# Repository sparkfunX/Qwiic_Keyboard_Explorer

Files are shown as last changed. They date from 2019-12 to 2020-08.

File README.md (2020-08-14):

Qwiic_Keyboard_Explorer
========================================

Qwiic Keyboard Explorer (https://cdn.sparkfun.com//assets/parts/1/4/8/4/8/16184-Qwiic_Keyboard_Explorer-01.jpg)

[*Qwiic Keyboard Explorer*](https://www.sparkfun.com/products/16184)

The Qwiic Keyboard Explorer is a 14-key mechanical keyboard kit based on our Qwiic Pro Micro development board. On its own, it makes a conveniently sized programmable macro pad, but we've also included plenty of prototyping space along the top for experimenting with all kinds of keyboard peripherals. If soldering isn't your thing, take advantage of the Pro Micro's Qwiic connector to attach any board from our Qwiic ecosystem! The standoff holes surrounding the prototyping area are spaced to accommodate most Qwiic boards for convenient mounting.

SparkFun labored with love to design this board. Feel like supporting open source hardware? 
Buy a [board](https://www.sparkfun.com/products/16184) from SparkFun!

Repository Contents
-------------------

* **/Hardware** - Eagle design files (.brd, .sch)
* **/Software** - Arduino Example Code

License Information
-------------------

This product is _**open source**_! 

Please review the LICENSE.md file for license information. 

If you have any questions or concerns on licensing, please contact technical support on our [SparkFun forums](https://forum.sparkfun.com/viewforum.php?f=152).

Distributed as-is; no warranty is given.

- Your friends at SparkFun.

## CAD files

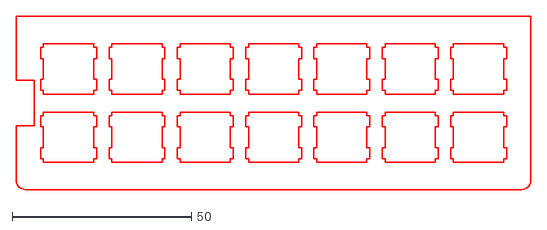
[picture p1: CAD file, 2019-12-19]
Hardware/Qwiic_Keyboard_Explorer.dxf
143.5 x 48.2

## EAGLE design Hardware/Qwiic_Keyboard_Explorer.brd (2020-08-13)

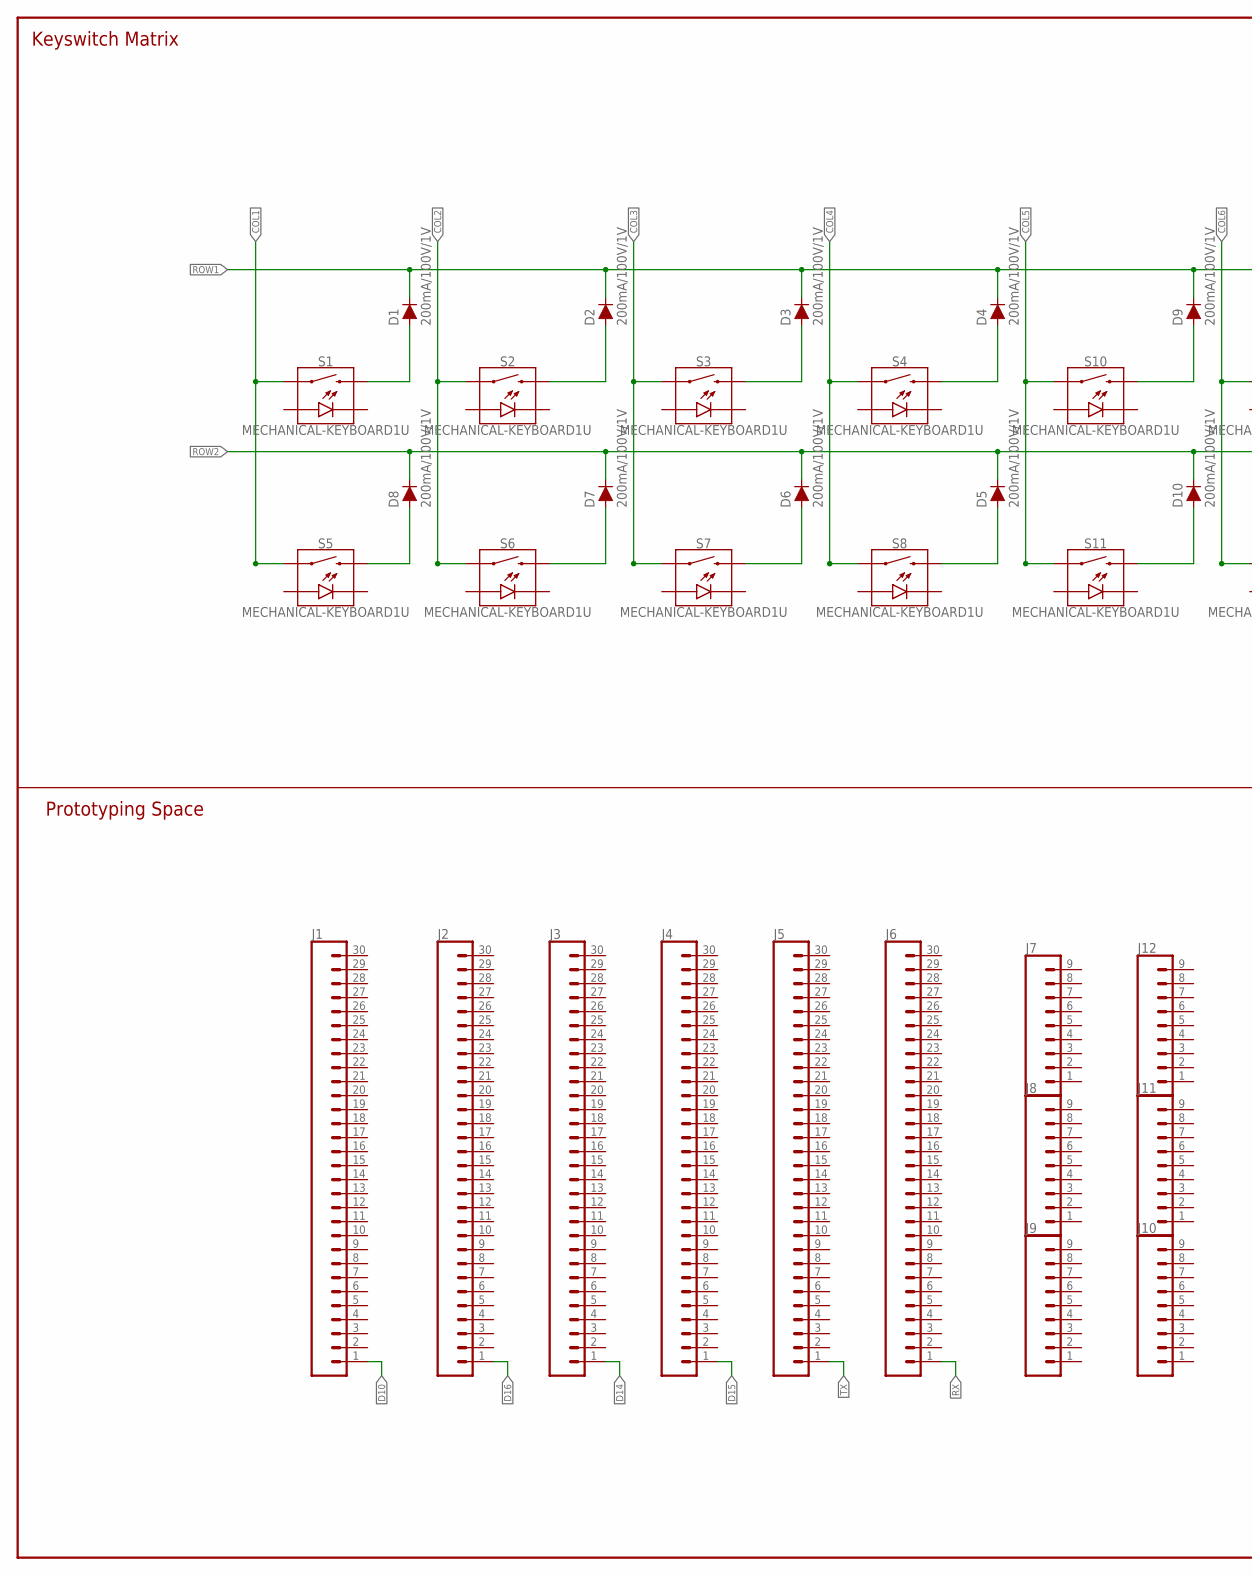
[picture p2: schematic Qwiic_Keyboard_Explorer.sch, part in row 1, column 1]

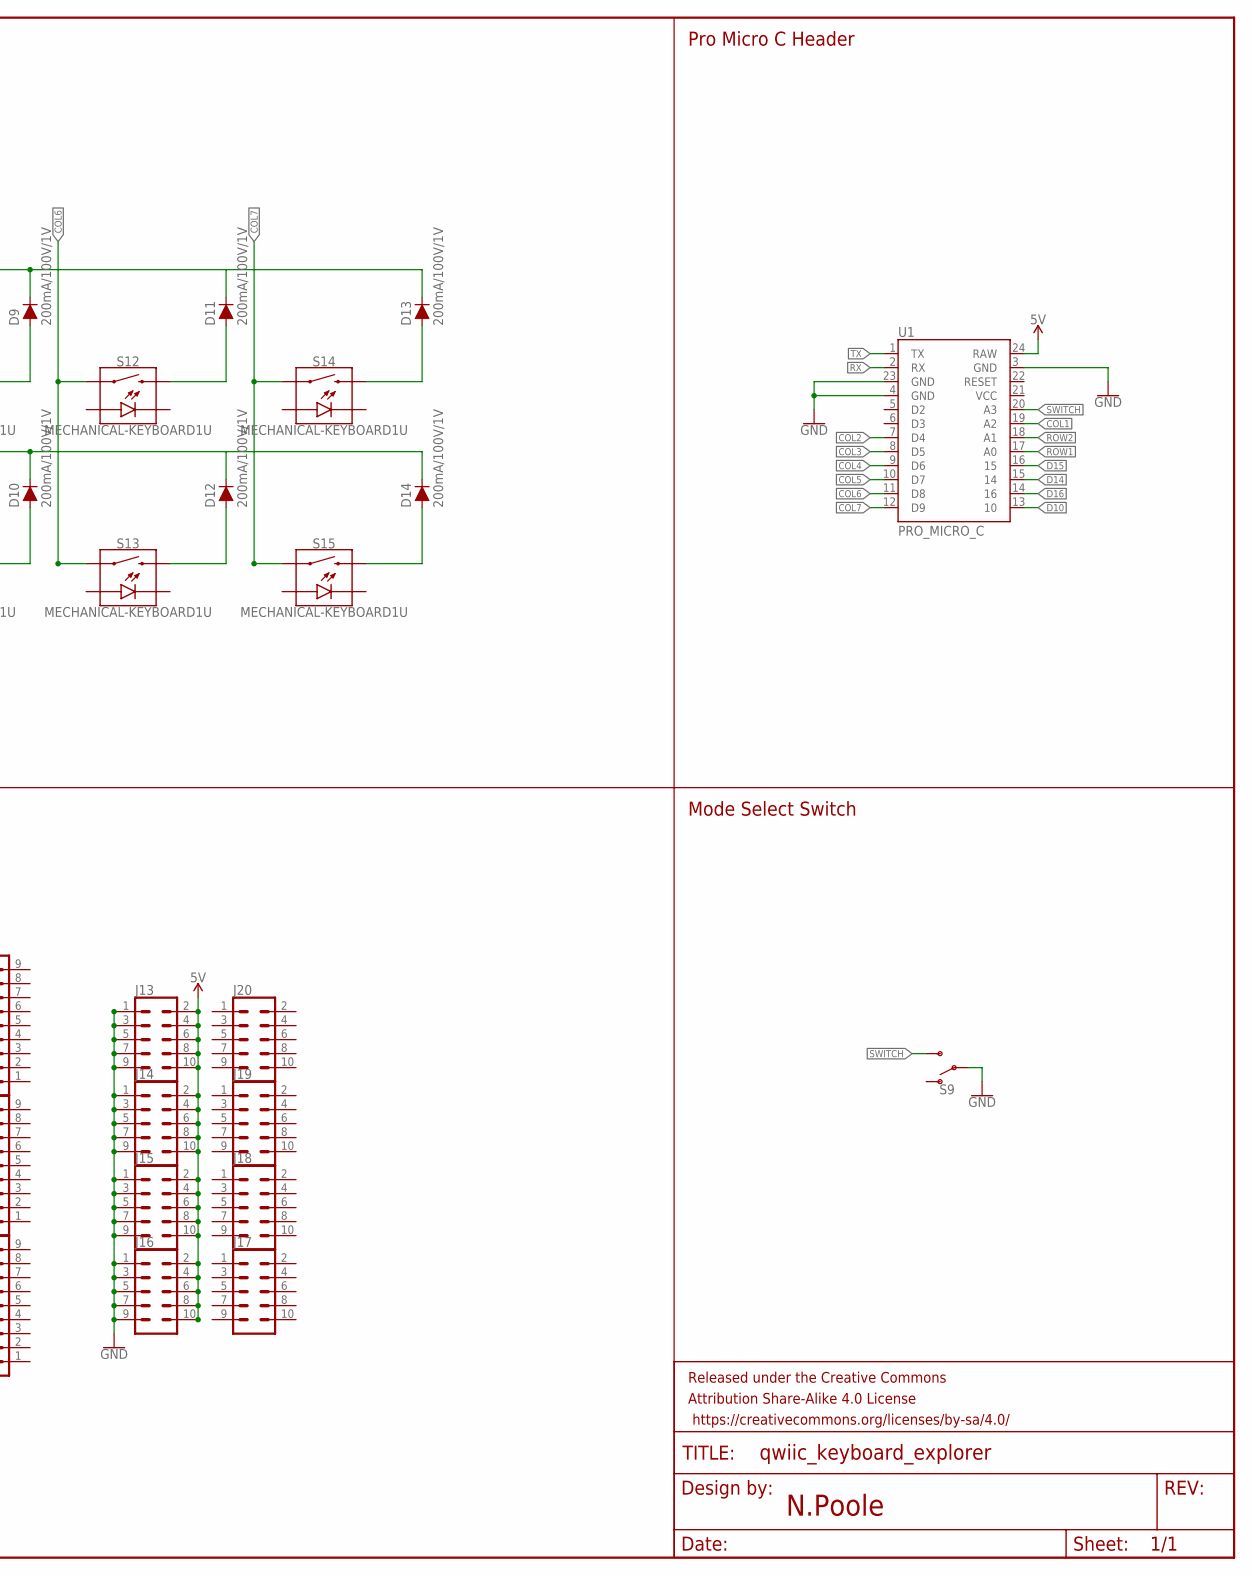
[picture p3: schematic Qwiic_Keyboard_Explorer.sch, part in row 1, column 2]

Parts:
D1, D2, D3, D4, D5, D6, D7, D8, D9, D10, D11, D12, D13, D14: 200mA/100V/1V; DIODE-1N4148-KIT
FRAME1: FRAME-LEDGER; CREATIVE_COMMONS
J1, J2, J3, J4, J5, J6: CONN_30NO_SILK; 1X30_NO_SILK
J7, J8, J9, J10, J11, J12: CONN_09NO_SILK; 1X09_NO_SILK
J13, J14, J15, J16, J17, J18, J19, J20: CONN_05X2NO_SILK; 2X5_NOSILK
S1, S2, S3, S4, S5, S6, S7, S8, S10, S11, S12, S13, S14, S15: MECHANICAL-KEYBOARD1U; CHERRY-MX-LED-1U
S9: SWITCH-SPDT-PTH-11.6X4.0MM-KIT; SWITCH_SPDT_PTH_11.6X4.0MM_KIT
U1: PRO_MICRO_C

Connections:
5V: J13.2, J13.4, J13.6, J13.8, J13.10, J14.2, J14.4, J14.6, J14.8, J14.10, J15.2, J15.4, J15.6, J15.8, J15.10, J16.2, J16.4, J16.6, J16.8, J16.10, U1.24 (RAW)
COL1: S1.S1 (1), S5.S1 (1), U1.19 (A2)
COL2: S2.S1 (1), S6.S1 (1), U1.7 (D4)
COL3: S3.S1 (1), S7.S1 (1), U1.8 (D5)
COL4: S4.S1 (1), S8.S1 (1), U1.9 (D6)
COL5: S10.S1 (1), S11.S1 (1), U1.10 (D7)
COL6: S12.S1 (1), S13.S1 (1), U1.11 (D8)
COL7: S14.S1 (1), S15.S1 (1), U1.12 (D9)
D10: J1.1, U1.13 (10)
D14: J3.1, U1.15 (14)
D15: J4.1, U1.16 (15)
D16: J2.1, U1.14 (16)
GND: J13.1, J13.3, J13.5, J13.7, J13.9, J14.1, J14.3, J14.5, J14.7, J14.9, J15.1, J15.3, J15.5, J15.7, J15.9, J16.1, J16.3, J16.5, J16.7, J16.9, S9.2, U1.3 (GND), U1.4 (GND), U1.23 (GND)
unnamed: D8.A, S5.S2 (2)
unnamed: D7.A, S6.S2 (2)
unnamed: D6.A, S7.S2 (2)
unnamed: D5.A, S8.S2 (2)
unnamed: D4.A, S4.S2 (2)
unnamed: D3.A, S3.S2 (2)
unnamed: D2.A, S2.S2 (2)
unnamed: D1.A, S1.S2 (2)
unnamed: D9.A, S10.S2 (2)
unnamed: D10.A, S11.S2 (2)
unnamed: D11.A, S12.S2 (2)
unnamed: D12.A, S13.S2 (2)
unnamed: D13.A, S14.S2 (2)
unnamed: D14.A, S15.S2 (2)
ROW1: D1.C, D2.C, D3.C, D4.C, D9.C, D11.C, D13.C, U1.17 (A0)
ROW2: D5.C, D6.C, D7.C, D8.C, D10.C, D12.C, D14.C, U1.18 (A1)
RX: J6.1, U1.2 (RX)
SWITCH: S9.3 (S), U1.20 (A3)
TX: J5.1, U1.1 (TX)

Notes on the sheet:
Keyswitch Matrix
Prototyping Space
Pro Micro C Header
Mode Select Switch
N.Poole

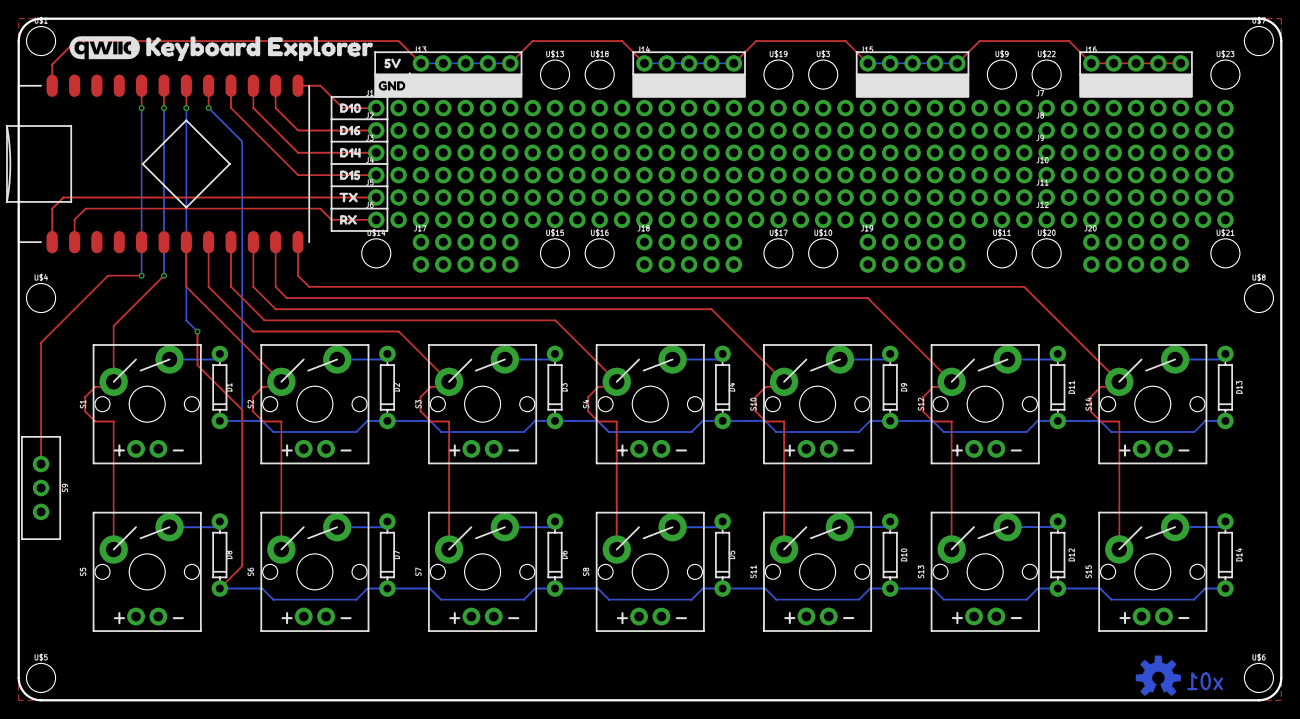
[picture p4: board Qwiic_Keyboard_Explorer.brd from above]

Board: 2 copper layers, 143.5 x 77.5 mm, 83 parts (1 on the bottom side), 32 nets.

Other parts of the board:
U$1, U$3, U$4, U$5, U$6, U$7, U$8, U$9, U$10, U$11, U$13, U$14, U$15, U$16, U$17, U$18, U$19, U$20, U$21, U$22, U$23: STAND-OFF
U$2: KEYBOARD_EXPLORER0
U$12: 5V0
U$24: QWIIC_8MM
U$25: GND-04
U$26: D101
U$27: D162
U$28: D143
U$29: D154
U$30: TX5
U$31: RX6
U$32: OSHW-LOGO-M_COPPER

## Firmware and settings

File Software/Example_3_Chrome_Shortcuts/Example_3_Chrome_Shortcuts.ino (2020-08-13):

/*
  Arduino USB Keyboard with Macros
  By: Nick Poole
  SparkFun Electronics
  Date: August 12th 2020
  License: This code is public domain but you buy me a beer if you use this and we meet someday (Beerware license).
  
  This example demonstrates how to program simple macros by implementing a Chrome shortcuts macro pad. This sketch will
  also monitor the mode switch on the Keyboard Explorer and toggle between acting as a keyboard and acting as
  a serial device.

  Here is the keypad layout for this sketch:

  -------------------------------------------------------------------------------------
  |   Go To   |   Go To   |   Go To   |   Go To   |   Go To   |   Go To   |   Go To   |
  |   Tab 1   |   Tab 2   |   Tab 3   |   Tab 4   |   Tab 5   |   Tab 6   |   Tab 7   |
  |           |           |           |           |           |           |           |
  -------------------------------------------------------------------------------------
  |   Go      |  Refresh  |  Go       |    New    |   Close   |   Tab     |   Tab     |
  |   Back    |   Page    |  Forward  |    Tab    |    Tab    |   Left    |   Right   |
  |           |           |           |           |           |           |           |
  -------------------------------------------------------------------------------------
  
*/

#include <Keypad_Matrix.h> //https://github.com/nickgammon/Keypad_Matrix
#include "Keyboard.h"


// Declare how many keys are on the keyboard
const byte ROWS = 2;
const byte COLS = 7;

// Define how the keypad is laid out
const char keys[ROWS][COLS] = {
  {0x01, 0x02, 0x03, 0x04, 0x05, 0x06, 0x07},
  {0x08, 0x09, 0x0A, 0x0B, 0x0C, 0x0D, 0x0E}
};

// These are the pin declarations for the Qwiic Keyboard Explorer
const byte rowPins[ROWS] = {A0, A1}; 
const byte colPins[COLS] = {A2, 4, 5, 6, 7, 8, 9}; 

// Keep track of which mode we're currently in
boolean kbdMode = false;

// Create the Keypad object
Keypad_Matrix kpd = Keypad_Matrix( makeKeymap (keys), rowPins, colPins, ROWS, COLS );

// Key Press Handler
void keyDown (const char which)
  {
  if(kbdMode){
    switch(which){

      // Switch to Tab 1
      case 0x01:
          Keyboard.press(KEY_LEFT_CTRL);
          Keyboard.press('1');
          delay(100);
          Keyboard.releaseAll();
        break;
      // Switch to Tab 2
      case 0x02:
          Keyboard.press(KEY_LEFT_CTRL);
          Keyboard.press('2');
          delay(100);
          Keyboard.releaseAll();
        break;
      // Switch to Tab 3
      case 0x03:
          Keyboard.press(KEY_LEFT_CTRL);
          Keyboard.press('3');
          delay(100);
          Keyboard.releaseAll();
        break;
      // Switch to Tab 4
      case 0x04:
          Keyboard.press(KEY_LEFT_CTRL);
          Keyboard.press('4');
          delay(100);
          Keyboard.releaseAll();
        break;
      // Switch to Tab 5
      case 0x05:
          Keyboard.press(KEY_LEFT_CTRL);
          Keyboard.press('5');
          delay(100);
          Keyboard.releaseAll();
        break;
      // Switch to Tab 6
      case 0x06:
          Keyboard.press(KEY_LEFT_CTRL);
          Keyboard.press('6');
          delay(100);
          Keyboard.releaseAll();
        break;
      // Switch to Tab 7
      case 0x07:
          Keyboard.press(KEY_LEFT_CTRL);
          Keyboard.press('7');
          delay(100);
          Keyboard.releaseAll();
        break;
      // Back
      case 0x08:
          Keyboard.press(KEY_LEFT_ALT);
          Keyboard.press(KEY_LEFT_ARROW);
          delay(100);
          Keyboard.releaseAll();
        break;
      // Reload
      case 0x09:
          Keyboard.press(KEY_LEFT_CTRL);
          Keyboard.press('r');
          delay(100);
          Keyboard.releaseAll();
        break;
      // Forward
      case 0x0A:
          Keyboard.press(KEY_LEFT_ALT);
          Keyboard.press(KEY_RIGHT_ARROW);
          delay(100);
          Keyboard.releaseAll();
        break;
      // Open new tab
      case 0x0B:
          Keyboard.press(KEY_LEFT_CTRL);
          Keyboard.press('t');
          delay(100);
          Keyboard.releaseAll();
        break;
      // Close tab
      case 0x0C:
          Keyboard.press(KEY_LEFT_CTRL);
          Keyboard.press('w');
          delay(100);
          Keyboard.releaseAll();
        break;
      // Tab left
      case 0x0D:
          Keyboard.press(KEY_LEFT_CTRL);
          Keyboard.press(KEY_LEFT_SHIFT);
          Keyboard.press(KEY_TAB);
          delay(100);
          Keyboard.releaseAll();
        break;
      // Tab right
      case 0x0E:
          Keyboard.press(KEY_LEFT_CTRL);
          Keyboard.press(KEY_TAB);
          delay(100);
          Keyboard.releaseAll();
        break; 
        
      }
    }
  }

// Check the mode switch position and change between USB-HID mode and Serial mode
void checkMode(){
  if(kbdMode){
    if(!digitalRead(A3)){
      kbdMode = false;
      Keyboard.end();
      SerialUSB.println("Keyboard in USB Serial Mode");
    }
  }else{
    if(digitalRead(A3)){
      kbdMode = true;
      SerialUSB.println("Keyboard entering HID Mode");
      Keyboard.begin();
    }    
  }
}


void setup()
{
  SerialUSB.begin(115200); // baud rate for Serial mode
  kpd.begin(); // initialise keyboard matrix
  kpd.setKeyDownHandler(keyDown); // declare keydown function
  pinMode(A3, INPUT_PULLUP); // initialize mode switch pin
}

void loop()
{
  kpd.scan(); // Get keyswitch statuses
  checkMode(); // Check mode switch
}

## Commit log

2019-12-19 Proto x01
    [Mounting_Plate.brd, Qwiic_Keyboard_Explorer.brd, Qwiic_Keyboard_Explorer.dxf]
2020-08-13 Aesthetic tweaks to eagle files
    [Qwiic_Keyboard_Explorer.brd, Qwiic_Keyboard_Explorer.sch]

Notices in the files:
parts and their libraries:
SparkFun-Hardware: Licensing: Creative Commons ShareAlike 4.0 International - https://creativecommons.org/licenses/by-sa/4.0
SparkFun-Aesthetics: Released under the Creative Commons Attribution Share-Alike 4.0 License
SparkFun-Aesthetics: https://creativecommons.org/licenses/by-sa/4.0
